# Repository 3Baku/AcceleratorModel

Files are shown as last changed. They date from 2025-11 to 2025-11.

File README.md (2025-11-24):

# AcceleratorModel
### Zamysł projektu
W tym repozytorium znajduje się wszystko potrzebne do stworzenia układu pomiaru prędkości (i średniej energii kinetycznej) dla modelu akceleratora bazującego na kulce ping-pongowej, salaterce i maszynie elektrostatycznej przedstawianego na warszatach podczas 2. Warszawskiej Konferencji Nauczycieli Fizyki (22.11.2025).

### Opis folderów
W folderze 'grafika' znajdują się pliki do programu KiCad 9.0 dzięki którym można wczytać schemat i edytować go dowolnie. Na podstawie tego pliku wygenerowany jest ./Schematy/ObwodSchemat.png.
Mieści się w nim README_schemat z ważnym komentarzem,
W folderze 'kody' znajduje się kod używany do poprawnego działania układu pomiarowego (który to poprzez np. Arduino IDE należy przesłać do Xiao C3 ESP32).
W folderze 'zdjęcia' można zobaczyć zbudowany układ pomairowy.
W folderze 'Schematy' mieści się flowchart kodu, ideowy schemat układu pomiarowego, oraz schemat obwodu używanego do pomiaru prędkości.

### Konwencje repozytorium
Wiadomości w commitach, schematy, oraz kod wraz z komentarzami do niego pisane są w języku angielskim,
Opisy pomocnicze oraz wymagania konstrukcyjne pisane są w języku polskim.

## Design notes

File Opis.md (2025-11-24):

# Akcelerator w salaterce — wersja rozszerzona

## Krótkie omówienie
Model "Akceleratora w salaterce" został wzbogacony o specjalne komponenty, które pozwoliły zamienić go na domowej roboty układ doświadczalny. Miskę będącą główną częścią akceleratora umieszczono w zbudowanej z klocków LEGO ramce z wydłużonymi szynami. Przyczepiono na nich z jednej strony laser, którego wiązka światła padała na umieszczony z drugiej strony fotorezystor. Pośrodku stała salaterka. Całkowita długość konstrukcji wyniosła około 69 cm. Taki układ pozwalał na odczytywanie momentu, w którym kulka przecinała wiązkę. W ten sposób — za pośrednictwem specjalnie napisanego kodu — można było odczytać czas, w którym kulka pokonywała pełne okrążenie. Znając promień, po jakim się poruszała, można było wyznaczyć jej prędkość. Po dokonaniu pomiaru masy kulki (niezbędna do tego będzie precyzyjna waga np. cukiernicza) możliwe jest obliczenie średniej energii kinetycznej tego obiektu podczas ruchu.

Do skonstruowania elektronicznej części układu została użyta lutownica wraz z cyną lutowniczą. Odpowiednie komponenty elektroniczne zostały połączone własnoręcznie na płytce drukowanej. Większość z nich została zakupiona z sklepu internetowego botland.

Wszystkie poniżej wymienione materiały oraz parametry odnoszą się do układu przedstawionego na zdjęciu, który to prezentowany był na II Warszawskiej Konferencji Nauczycieli Fizyki.
## Spis materiałów do podstawowej wersji akceleratora
* Miska typu salaterka (najlepiej z płaskim dnem i kolistym kształtem)
* Taśma miedziana (można znaleźć jako "na ślimaki") [1]
* 6 kabli typu krokodylki
* Maszyna elektrostatyczna
* Piłeczki pingpongowe
* Spray grafitowy [2]
## Spis materiałów do rozszerzonej wersji — pomiar prędkości
* Przewód zasilający sterowanie
* Dioda laserowa 3–5V 5mW czerwona 650nm [3]
* Fotorezystor 100–200k (można dobrać mniejszy) [4]
* Tranzystor NMOS 2N7000 [5]
* Mikrokontroler Xiao ESP32-C3 [6]
* Płytka drukowana do lutowania (opcjonalnie można stworzyć projekt PCB na podstawie pliku KiCad [7]
* Rezystory: jeden 10k, oraz jeden 1k
* Lutownica
* Cyna lutownicza (np. Sn60Pb40)
* Przewody do łączenia pól lutowniczych

## Parametry niezbędne do obliczeń
* Masa kulki — 2,74 g
* Promień salaterki — 6,5 cm

## Zdjęcie układu doświadczalnego

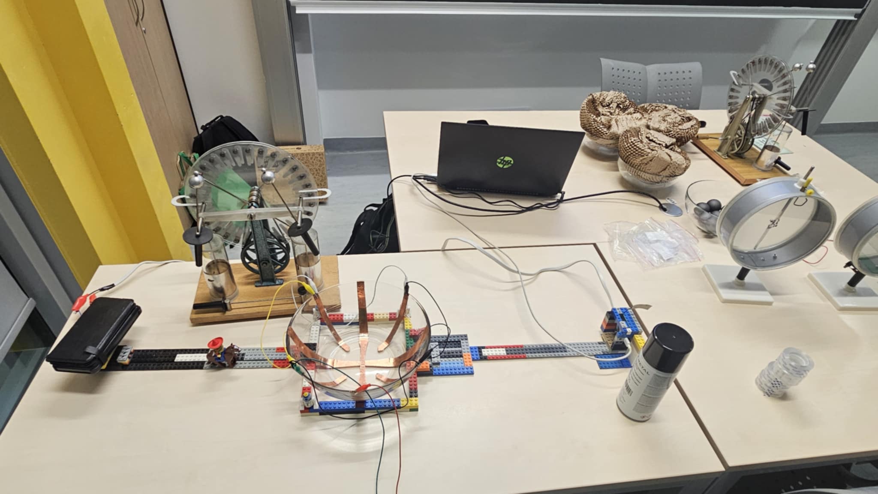
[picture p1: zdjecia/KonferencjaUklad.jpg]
Zdjecie ukladu z konferencji

## Linki

[1] [Taśma miedziana](https://allegro.pl/oferta/tasma-miedziana-na-slimaki-odstraszajaca-samoprzylepna-20m-x-25mm-miedz-18013162639?offerId=18013162639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)

[2] [Spray grafitowy](https://allegro.pl/produkt/farba-przewodzaca-grafitowa-spray-400ml-antystatyczna-ekranujaca-uziemienie-96ab1be1-56a6-4b00-8113-e29869f06b20?offerId=16966271625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)

[3] [Dioda laserowa](https://botland.com.pl/diody-laserowe/6450-dioda-laserowa-5mw-czerwona-650nm-5v-5904422359782.html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)

[4] [Fotorezystor](https://elektronika-sklep.pl/optoelektronika/fotoelementy/fotorezystory/fotorezystor-5mm-100-200k/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)

[5] [Tranzystor](https://elektronika-sklep.pl/polprzewodniki/tranzystory/tranzystory-unipolarne/tranzystory-z-kanaem-typu-n/2n7000/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)

[6] [Mikrokontroler](https://botland.com.pl/moduly-wifi-i-bt-esp32/21859-seeed-xiao-esp32-c3-wifibluetooth-seeedstudio-113991054.html)

[7] [Płytka drukowana do lutowania](l.messenger.com/l.php?u=https%3A%2F%2Fbotland.com.pl%2Fplytki-uniwersalne%2F2744-plytka-drukowana-uniwersalna-dwustronna-40x60mm-5904422303297.html&h=AT0iM1pIM4rylPPTv-ln3OiRvIT1WWi_INN2hKSjnTGUCpENc7v5Qc4CKn1a4ZpNlS-LD7xwWBBMzHVcvjrNCfumq-jdFOZivjr0glafdcMqE_LVTLSooL7hBR4sf2ZCY3R-NQ)

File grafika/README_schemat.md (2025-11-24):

 # PCB
 PCB nie zostało wykonane — kupiona była zwykła płytka z otworami do lutowania THT. W razie posiadania czasu i finansów, wysoce zachęcane jest stworzenie własnego PCB na podstawie schematu, jednakże pamiętać należy o tym, aby nie wbudowywać lasera do płytki, tylko aby był podłączony na odległość od fotorezystora.
# Alternatywne układy
 Możliwym jest stworzenie układu w znacząco prostrzy sposób — rozdzielając układ zasilania lasera od ESP32. Wymagane byłoby umiejętne dobranie rezystora, oraz źródła zasilania (3–5V) do lasera. 
 W tym projekcie laser został połączony poprzez układ wzmacniający MOS ze względu na możliwość przyszłego rozwoju, tj. wyłączania lasera za pomocą przesyłanej strony.

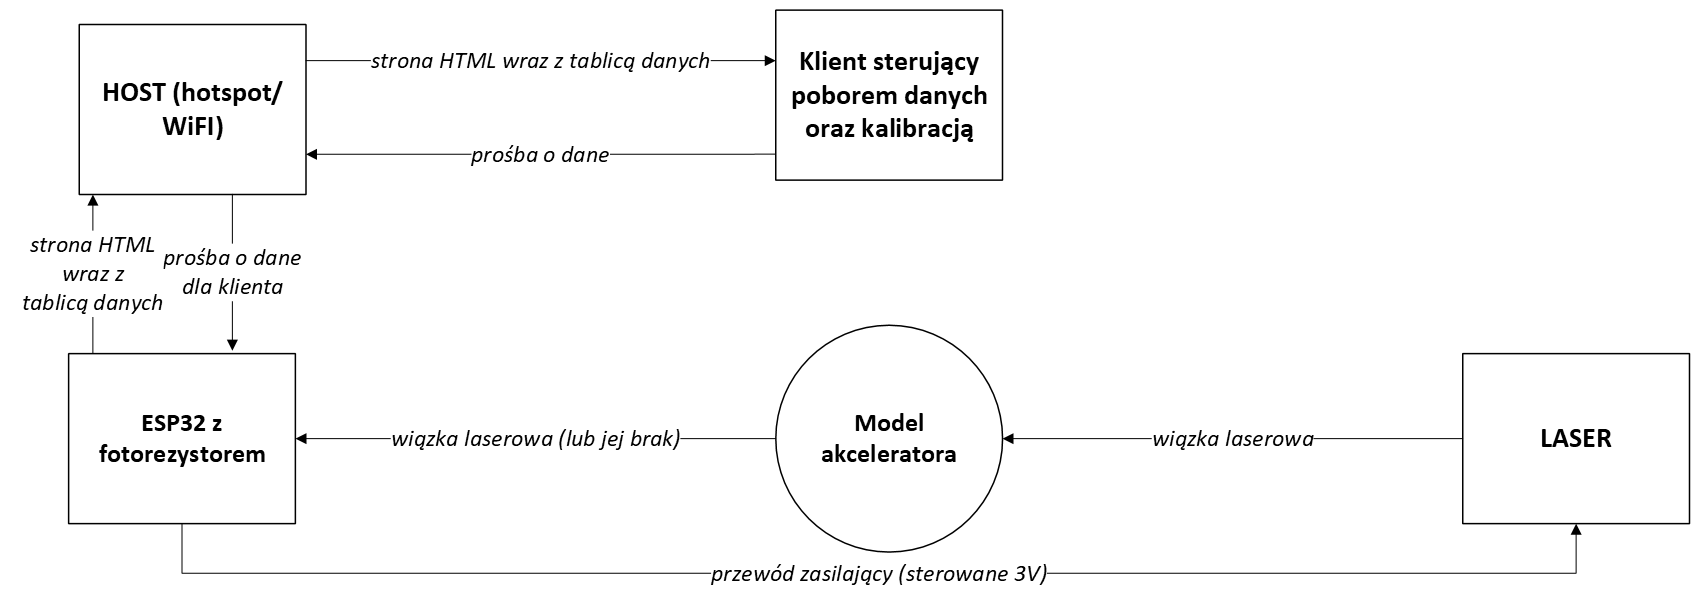
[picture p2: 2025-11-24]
Schematy/UkladPomiarowySchemat.png

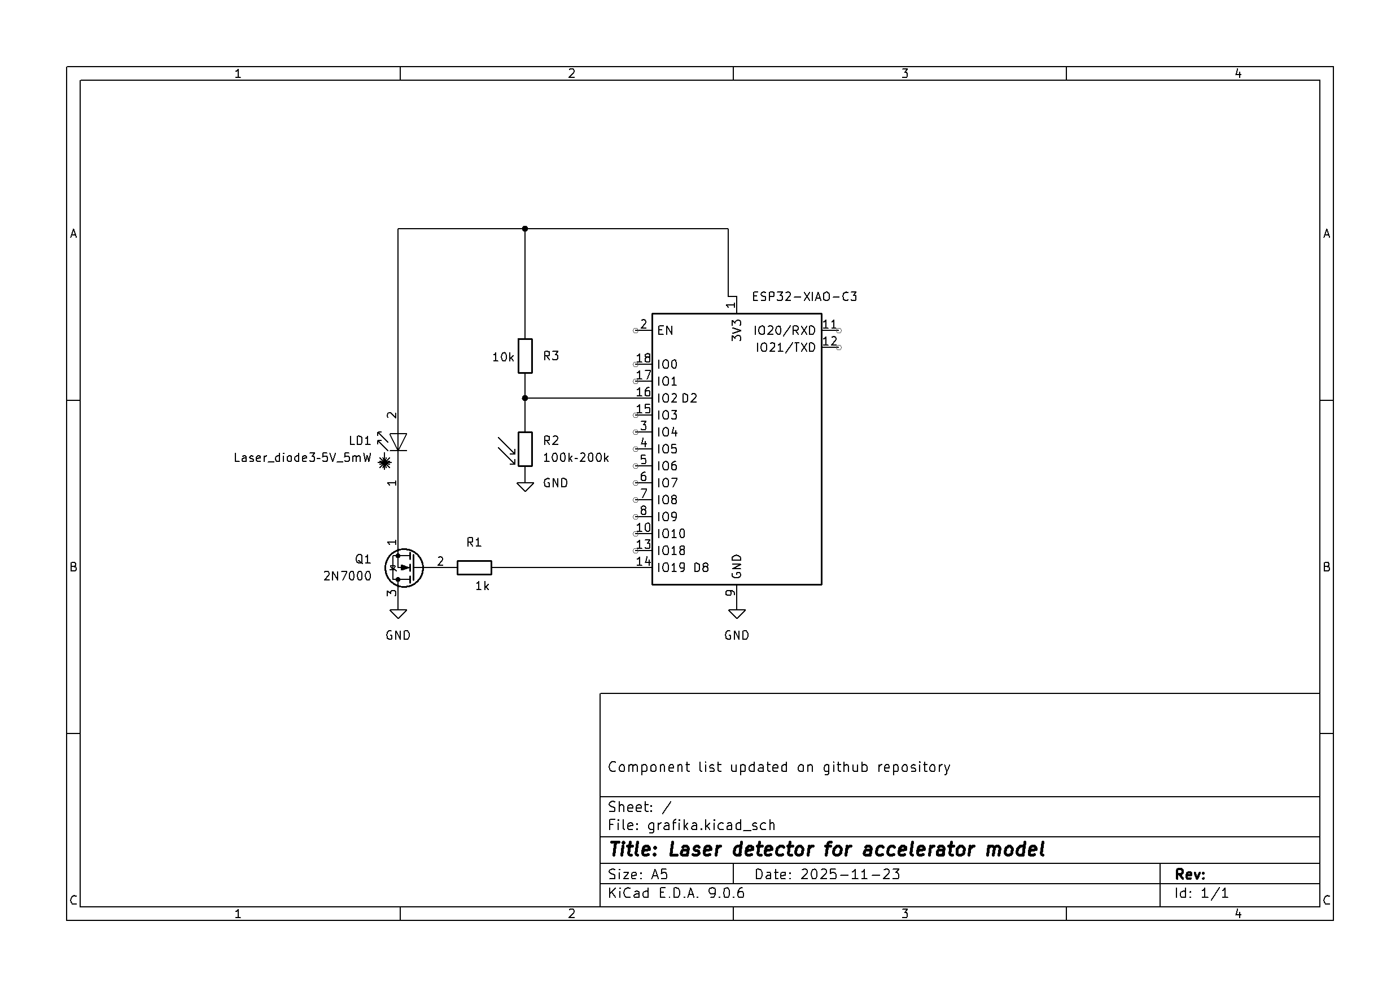
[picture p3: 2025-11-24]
Schematy/ObwodSchemat.png

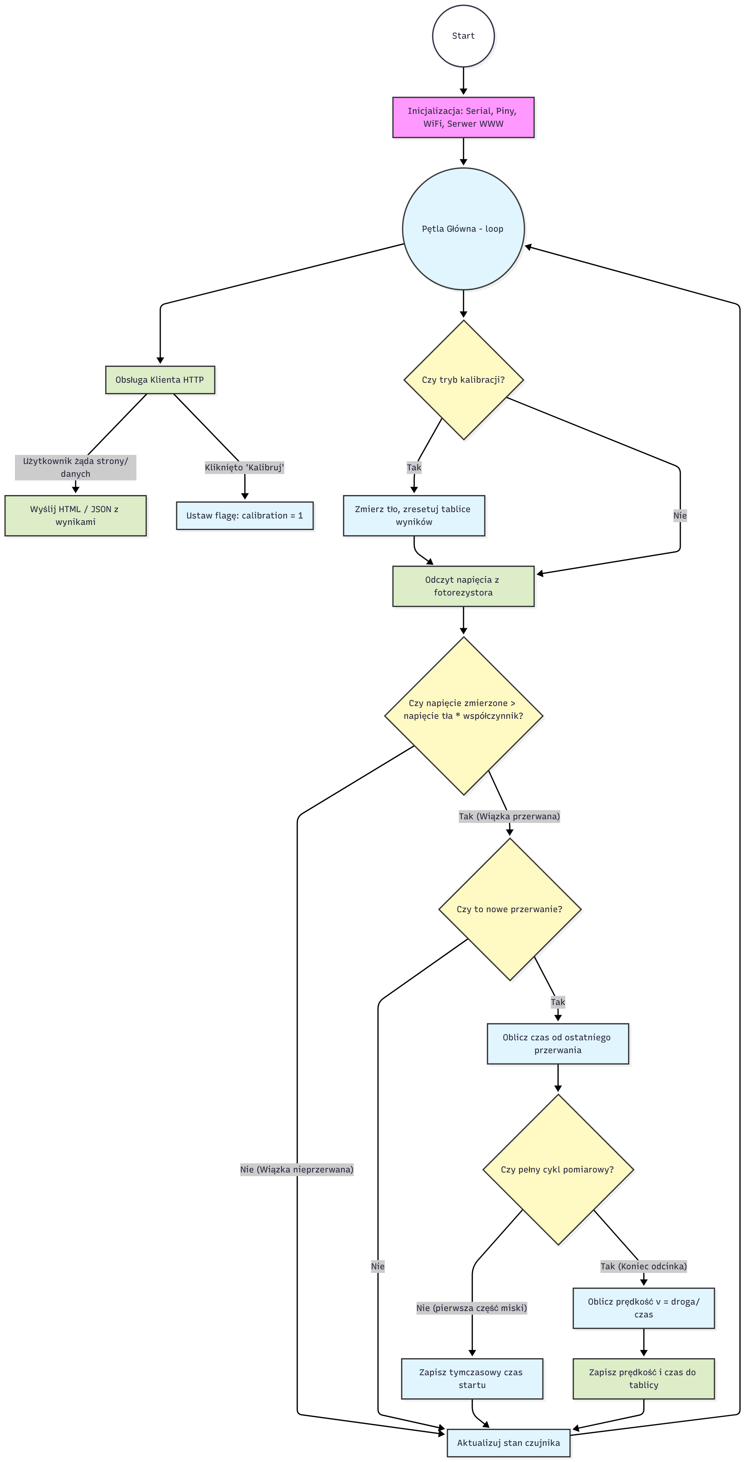
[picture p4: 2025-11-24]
Schematy/codeFlowChart.png

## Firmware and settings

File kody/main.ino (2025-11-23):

#include <WiFi.h>
#include "wifipass.h"
#include <WebServer.h>
#include "webpage.h"
WebServer server(80);

const short numberOfMeasurements = 100;
const float onOffAspectRatio = 0.8;  //how much of calibrated V is considered open circuit
const float radius = 6.5; //in cm
const float mass = 2.74; //in grams
const float circumference = 2*radius*3.1415;
const int laserPin = D9; 
const int photoPin = D2;

bool calibration = 1;
bool showPlot = 0;
//states define 0 as being no barrier/closed circuit
bool currentState = 0;
bool lastState = 0;

unsigned short velocityIndex = 0;
unsigned long currentMillis = 0;
unsigned long duration = 0;
unsigned long duration_tmp = 0;
float velocity = 0.0;
unsigned long lastChangeTime = 0;
float calibratedVoltages = 0;
bool isEvenReading = 0; //used, because two measurenments per one circle

float velocityArray[numberOfMeasurements] = {0.0};
unsigned long durationArray[numberOfMeasurements] = {0}; 

// --- JSON GENERATORS ---

// Simple Array for first plot [v1, v2, v3]
String get_array_string() {
  String json = "[";
  for (int i = 0; i < velocityIndex; i++) {
    json += String(velocityArray[i]);
    if (i < velocityIndex - 1) json += ",";
  }
  json += "]";
  return json; 
}

// V,t object Array for plot 2: [{x:0, y:10}, {x:50, y:12}]
String get_xy_data_string() {
  String json = "[";
  for (int i = 0; i < velocityIndex; i++) {
    json += "{x:";
    json += String(durationArray[i]);
    json += ",y:";
    json += String(velocityArray[i]);
    json += "}";
    if (i < velocityIndex - 1) json += ",";
  }
  json += "]";
  return json;
}

float get_average_voltage(int pin, int numOfMeasurements) {
  long totalValue = 0;
  for (int i = 0; i < numOfMeasurements; i++) {
    totalValue += analogRead(pin);
  }
  return ((float)totalValue / numOfMeasurements) * (3.3 / 4095.0);
}

void calibrate_sensor(){
  calibratedVoltages = get_average_voltage(photoPin, 10);
  Serial.print("--- CALIBRATION DONE: ");
  Serial.println(calibratedVoltages);
}

unsigned long calculate_duration(){
  currentMillis = millis();    
  duration_tmp = currentMillis - lastChangeTime;
  return duration_tmp;
}

float calculate_velocity(){
  if(duration == 0) return 0; 
  return circumference/(duration/1000.0);
}


float calc_avg_velocity(){
  float sum = 0;
  if (velocityIndex == 0) return 0.0;
  
  for(int i = 0; i < velocityIndex; i++) {
    sum += velocityArray[i];
  }
  return sum / velocityIndex;
}

float calc_avg_ekin(float avgVel){
  return 0.05 * mass * avgVel * avgVel;
}

void setup() {
  Serial.begin(115200);
  pinMode(laserPin, OUTPUT);
  digitalWrite(laserPin, HIGH); 
  pinMode(photoPin, INPUT);
  connect_to_Wifi();
  server_setup();
}

void loop() {
  server.handleClient();

  if(calibration == 1) {
    calibrate_sensor();
    calibration = 0;   
    currentState = 0;
    velocityIndex = 0;
    for(int i=0; i<numberOfMeasurements; i++) {
       velocityArray[i] = 0; 
       durationArray[i] = 0;
    }
  }
  
  float voltage = get_average_voltage(photoPin, 5);
  
  // Open circuit
  if(voltage * onOffAspectRatio > calibratedVoltages){
    lastState = currentState;
    currentState = 1;
  } else {
    lastState = currentState;
    currentState = 0;
  }

  if(!lastState && currentState){
    if (velocityIndex < numberOfMeasurements) {

      if(isEvenReading){
        duration = calculate_duration();
        lastChangeTime = currentMillis;
        isEvenReading = 0;
      }
      else{
        duration += calculate_duration();
        lastChangeTime = currentMillis;
        
        unsigned long prevTime = (velocityIndex == 0) ? 0 : durationArray[velocityIndex-1];
        durationArray[velocityIndex] = prevTime + duration;
        
        velocityArray[velocityIndex] = calculate_velocity();
        Serial.println("New velocity saved");
        velocityIndex++;
        isEvenReading = 1;
      }
      
    } else {
        // Serial.println("Memory Full!"); 
    }
    lastState = currentState;
  }
  
}

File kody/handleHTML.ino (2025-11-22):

String processor(const String& var) {
  
  // 1. Standard Array (Graph 1)
  if(var == "DATA_ARRAY") {
    if (showPlot) return get_array_string();
    else return "[]";
  }

  // 2. XY Data (Graph 2)
  if(var == "XY_DATA") {
    if (showPlot) return get_xy_data_string();
    else return "[]";
  }

  // 3. Statistics Section
  if(var == "STATS_HTML") {
    if (!showPlot || velocityIndex == 0) return "No data available.";
    
    float avgV = calc_avg_velocity();
    float avgE = calc_avg_ekin(avgV);
    
    String stats = "Average Velocity: <span class='val'>" + String(avgV) + " cm/s</span><br>";
    stats += "Avg. Kinetic Energy: <span class='val'>" + String(avgE) + " uJ</span>";
    return stats;
  }

  // 4. Buttons
  if(var == "BUTTON_1") {
    if(calibration) return F("<button class='btn btn-calib' disabled>BUSY...</button>");
    return F("<a href='/calibrate'><button class='btn btn-calib'>CALIBRATE</button></a>");
  }

  if(var == "BUTTON_2") {
    if (showPlot) return F("<a href='/plot'><button class='btn btn-plot'>UPDATE PLOT</button></a>");
    else return F("<a href='/plot'><button class='btn btn-plot'>PLOT DATA</button></a>");
  }

  return String();
}

void handle_root() {
    String s = index_html;
    s.replace("%DATA_ARRAY%", processor("DATA_ARRAY"));
    s.replace("%XY_DATA%", processor("XY_DATA")); // Replaces new placeholder
    s.replace("%STATS_HTML%", processor("STATS_HTML")); // Replaces stats
    s.replace("%BUTTON_1%", processor("BUTTON_1"));
    s.replace("%BUTTON_2%", processor("BUTTON_2"));
    server.send(200, "text/html", s);
}

void handle_calibrate() {
    calibration = 1;
    showPlot = 0;
    server.sendHeader("Location", "/");
    server.send(303);
}

void handle_plot() {
  showPlot = 1;
  server.sendHeader("Location", "/");
  server.send(303);
}

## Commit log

2025-10-18 Implement distance and velocity measurement for 6cm
    Added distance measurement and velocity calculation based on ultrasonic sensor readings.
2025-11-05 Changed from uno into ESP32. Added scheme
2025-11-05 Changed uno to esp32
2025-11-06 Added schematics of the circuit with esp32, made in kicad
    [grafika.kicad_pcb, grafika.kicad_sch]
2025-11-22 Added new folders. Changed everything to work with webUI, added velocity calculations and corrected mistakes while making the codes much clearer
    [handleHTML.ino, main.ino]
2025-11-22 Added new plot and averages to properly show on website. Fixed small bugs. Made a huge change in speed of receiving
    [handleHTML.ino, main.ino]
2025-11-24 Added new Schematics and updated README.md accordingly. Chaged KiCad to be more precise.
    [grafika.kicad_sch]
2025-11-24 Updated the repo for open access
    Changed the WARNING telling readers to not use the repos descriptions yet — because they have been fully updated and now the repo is ready for use
